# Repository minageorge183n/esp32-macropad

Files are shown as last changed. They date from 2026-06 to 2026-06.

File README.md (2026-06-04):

# 🔘 ESP32 Bluetooth + WiFi Macropad

A custom-built macropad featuring **9 programmable keys** and **2 rotary encoders**, designed for productivity, streaming, editing, and general automation.
It connects via **Bluetooth** for real-time input and **WiFi** for easy configuration through a web-based UI.

---

## ✨ Features

* 🎹 **9 Mechanical Keys**
  Fully programmable keys that can send:

  * Keyboard shortcuts
  * Media controls
  * Text strings

* 🔄 **2 Rotary Encoders**
  Each encoder supports:

  * Clockwise / Counterclockwise rotation
  * Push button click

* 📡 **Dual Connectivity**

  * **Bluetooth (BLE)** → Acts as a wireless keyboard
  * **WiFi** → Hosts a configuration web interface

* 🌐 **Web UI Configuration**

  * Access via browser (phone or PC)
  * Remap keys and encoders 
  * No need to reflash firmware for changes

---

## ⚙️ How It Works

### Bluetooth Mode

* The macropad connects to your device as a **BLE keyboard**
* Pressing keys sends predefined actions instantly

### WiFi Mode

* The device creates or connects to a WiFi network
* You access a **local web page** hosted on the ESP32
* From there, you can:

  * Change key mappings
  * Assign new actions
  * Save configurations

---

## 🚀 Getting Started

### 1. Power On

* Connect the macropad via USB or battery
* It will automatically start Bluetooth and WiFi services

### 2. Connect via Bluetooth

* Pair it like a normal keyboard
* Start using default key mappings

### 3. Access Web Interface

* Connect to the same WiFi network (or device hotspot mode)
* Open browser and go to:

  ```
  http://<device-ip>
  ```
* Configure keys and encoders from the UI

---

## 🧠 Key Mapping Capabilities

Each key can be configured to:

* 🔹 Send a single key (e.g., `A`, `Enter`)
* 🔹 Use modifiers (`Ctrl`, `Alt`, `Shift`)
* 🔹 Trigger media actions (volume, play/pause)
* 🔹 Type full strings (macros)

---

## 🎛️ Rotary Encoder Functions

Each encoder supports:

* ↻ Rotate Left → Action 1
* ↺ Rotate Right → Action 2
* ⏺ Press → Action 3

Example uses:

* Volume control
* Timeline scrubbing
* Zoom in/out

---

## 🛠️ Hardware Overview

* ESP32 microcontroller
* 9 mechanical switches
* 2 rotary encoders with push buttons
* Optional battery module

---

## 📌 Use Cases

* 🎥 Streaming (OBS, shortcuts)
* 🎨 Design (Photoshop, Illustrator)
* 🎬 Video editing (Premiere, DaVinci)
* 💻 General productivity
* 🎮 Gaming macros

---

## 🔮 Future Improvements

* Profiles switching
* OLED display support
* Cloud sync for configs
* Mobile app companion

---

## 📄 Notes

* Make sure Bluetooth is enabled on your device
* Web UI works best on modern browsers
* Keep firmware updated for new features

---

## 🤝 Contributing

This is a personal project, but ideas and improvements are always welcome.

---

## 📜 License

---

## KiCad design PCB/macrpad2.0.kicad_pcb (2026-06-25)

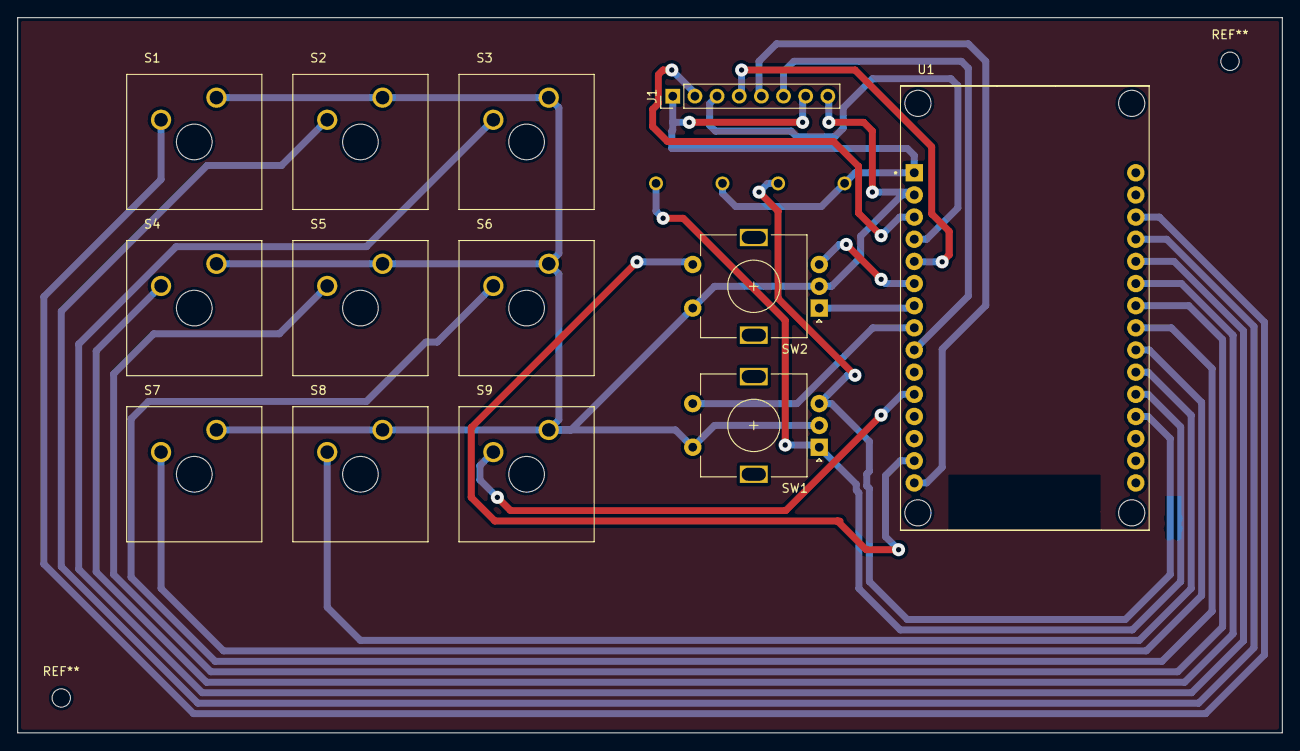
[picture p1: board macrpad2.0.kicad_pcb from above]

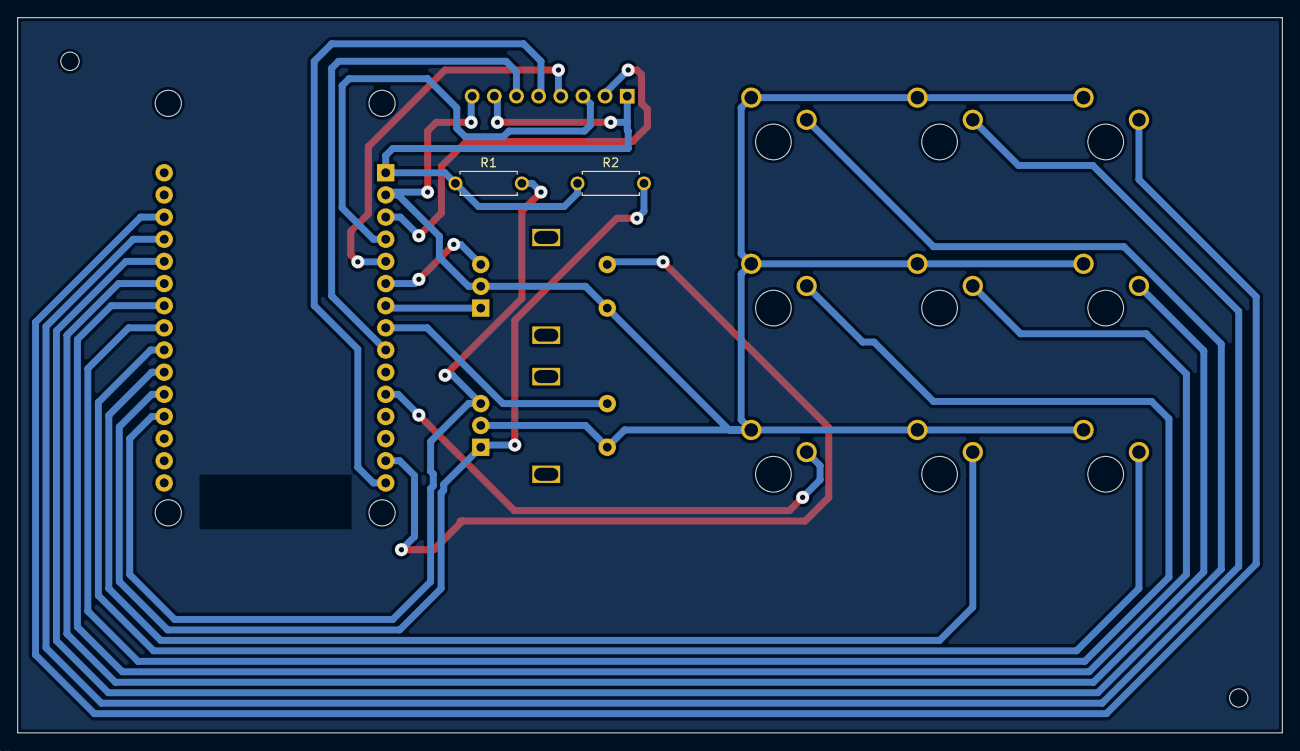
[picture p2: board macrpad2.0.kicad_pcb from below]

Board: 2 copper layers, 145.0 x 82.0 mm, 15 parts (2 on the bottom side), 22 nets.

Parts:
J1: Conn_01x08_Pin; PinHeader_1x08_P2.54mm_Vertical
R1, R2: Resistor; R_Axial_DIN0207_L6.3mm_D2.5mm_P7.62mm_Horizontal
S1, S2, S3, S4, S5, S6, S7, S8, S9: SW_MX1A-11NN
SW1, SW2: RotaryEncoder_Switch; RotaryEncoder_Alps_EC11E-Switch_Vertical_H20mm
U1: DEVKIT_V1_ESP32-WROOM-32; MODULE_DEVKIT_V1_ESP32-WROOM-32

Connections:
/d12: S2.1, U1.27 (D12)
/d13: S1.1, U1.28 (D13)
/d14: S3.1, U1.26 (D14)
GND: J1.8, S1.2, S2.2, S3.2, S4.2, S5.2, S6.2, S7.2, S8.2, S9.2, SW1.C, SW1.S2, SW2.C, SW2.S2, U1.2 (GND), U1.29 (GND)
unnamed: J1.1, J1.7, R1.1, R2.1, U1.1 (3V3)
unnamed: J1.2, U1.3 (D15)
unnamed: J1.3, U1.4 (D2)
unnamed: J1.4, U1.5 (D4)
unnamed: J1.5, U1.15 (D23)
unnamed: J1.6, U1.9 (D18)
unnamed: SW1.S1, U1.8 (D5)
unnamed: S9.1, U1.11 (D21)
unnamed: SW2.S1, U1.14 (D22)
unnamed: S6.1, U1.23 (D25)
unnamed: S5.1, U1.24 (D26)
unnamed: S4.1, U1.25 (D27)
unnamed: S8.1, U1.21 (D32)
unnamed: S7.1, U1.22 (D33)
unnamed: R1.2, SW1.B, U1.19 (D34)
unnamed: R2.2, SW1.A, U1.20 (D35)
unnamed: SW2.B, U1.6 (RX2)
unnamed: SW2.A, U1.7 (TX2)

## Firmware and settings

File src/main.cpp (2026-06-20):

#include <Arduino.h>
#include <BleKeyboard.h>
#include "macropad.h"
#include "keys.h"
#include "keymap.h"
#include "display.h"
#include "games.h"

BleKeyboard ble("Macropad", "DIY", 100);

// ── Debounce state ────────────────────────────────────────────
struct KeyDebounce {
  bool     confirmed;
  bool     raw;
  uint32_t lastChangeMs;
};

KeyDebounce keys[NUM_KEYS] = {};
KeyDebounce modeKey        = {};
uint8_t     currentMode    = 0;
bool        bleWasConnected = false;

// ── Rotary encoder state ──────────────────────────────────────
struct Encoder {
  int      pinCLK, pinDT, pinSW;
  int      lastCLK;
  bool     swConfirmed;
  bool     swRaw;
  uint32_t swLastChangeMs;
};

Encoder enc1 = { ENC1_CLK, ENC1_DT, ENC1_SW, HIGH, false, false, 0 };
Encoder enc2 = { ENC2_CLK, ENC2_DT, ENC2_SW, HIGH, false, false, 0 };

// ── Setup ─────────────────────────────────────────────────────
void setup() {
  Serial.begin(115200);

  for (int i = 0; i < NUM_KEYS; i++)
    pinMode(KEY_PINS[i], INPUT_PULLUP);

  pinMode(ENC1_CLK, INPUT);
  pinMode(ENC1_DT,  INPUT);
  pinMode(ENC1_SW,  INPUT_PULLUP);
  pinMode(ENC2_CLK, INPUT_PULLUP);
  pinMode(ENC2_DT,  INPUT_PULLUP);
  pinMode(ENC2_SW,  INPUT_PULLUP);

  enc1.lastCLK = digitalRead(ENC1_CLK);
  enc2.lastCLK = digitalRead(ENC2_CLK);

  displayInit();
  gamesInit(&tft);
  ble.begin();

  screenDirty = true;
  Serial.println("Macropad ready");
}

// ── Debounce helpers ──────────────────────────────────────────
bool debounce(KeyDebounce& k, bool reading) {
  uint32_t now = millis();
  if (reading != k.raw) { k.raw = reading; k.lastChangeMs = now; return false; }
  if ((now - k.lastChangeMs) >= DEBOUNCE_MS) {
    bool prev = k.confirmed; k.confirmed = k.raw;
    return k.raw && !prev;
  }
  return false;
}

bool debounceEncSW(Encoder& e) {
  uint32_t now     = millis();
  bool     reading = (digitalRead(e.pinSW) == LOW);
  if (reading != e.swRaw) { e.swRaw = reading; e.swLastChangeMs = now; return false; }
  if ((now - e.swLastChangeMs) >= DEBOUNCE_MS) {
    bool prev = e.swConfirmed; e.swConfirmed = e.swRaw;
    return e.swRaw && !prev;
  }
  return false;
}

int pollEncoder(Encoder& e) {
  int clk = digitalRead(e.pinCLK);
  if (clk == e.lastCLK) return 0;
  delayMicroseconds(500);
  clk = digitalRead(e.pinCLK);
  if (clk == e.lastCLK) return 0;
  e.lastCLK = clk;
  return (clk == digitalRead(e.pinDT)) ? 1 : -1;
}

// ── BLE action dispatch ───────────────────────────────────────
void executeAction(const KeyAction& action) {
  if (!ble.isConnected()) return;
  switch (action.type) {
    case KEY_SINGLE:
      for (uint8_t mod : action.modifiers) if (mod) ble.press(mod);
      ble.press(action.keycode);
      delay(10); ble.releaseAll();
      break;
    case KEY_MEDIA:
      ble.press(action.mediaKeycode);
      delay(10); ble.releaseAll();
      break;
    case KEY_STRING:
      ble.print(action.str);
      break;
    default: break;
  }
}

void executeEncoderAction(const EncoderAction& action) {
  if (!ble.isConnected()) return;
  switch (action.type) {
    case ENC_MEDIA:
      ble.press(action.mediaKeycode);
      delay(10); ble.releaseAll();
      break;
    case ENC_SINGLE:
      for (uint8_t mod : action.modifiers) if (mod) ble.press(mod);
      ble.press(action.keycode);
      delay(10); ble.releaseAll();
      break;
    default: break;
  }
}

// ── Loop ──────────────────────────────────────────────────────
void loop() {

  bool bleConnected = ble.isConnected();

  if (bleConnected != bleWasConnected) {
    bleWasConnected = bleConnected;
    screenDirty = true;
  }
  if (gamesTick()) return;

  // ── 9 keys ──────────────────────────────────────────────────
  for (int i = 0; i < NUM_KEYS; i++) {
    if (debounce(keys[i], digitalRead(KEY_PINS[i]) == LOW)) {
      const KeyAction& action = keymap[currentMode][i];
      Serial.printf("Key %d [mode %d] → %s\n", i, currentMode, action.label);
      executeAction(action);
      displaySetLastAction(action.label, i);   // pass key index for highlight
    }
  }

  // ── Encoder 1 — Volume (constant) ───────────────────────────
  int d1 = pollEncoder(enc1);
  if (d1 != 0) {
    if (d1 > 0) {
      Serial.println("Enc1 CW  → Vol+");
      ble.press(KEY_MEDIA_VOLUME_UP);
      displaySetLastAction("Vol+");   // 0xFF key = no cell highlight
    } else {
      Serial.println("Enc1 CCW → Vol-");
      ble.press(KEY_MEDIA_VOLUME_DOWN);
      displaySetLastAction("Vol-");
    }
    delay(10); ble.releaseAll();
  }
  if (debounceEncSW(enc1)) {
    Serial.println("Enc1 SW  → Mute");
    ble.press(KEY_MEDIA_MUTE);
    delay(10); ble.releaseAll();
    displaySetLastAction("Mute");
  }

  // ── Encoder 2 — Mode-aware; SW = mode change ─────────────────
  int d2 = pollEncoder(enc2);
  if (d2 != 0) {
    const EncoderMode& em = enc2Modes[currentMode];
    if (d2 > 0) {
      Serial.printf("Enc2 CW  [mode %d]\n", currentMode);
      executeEncoderAction(em.cw);
      displaySetLastAction("Enc2 CW");
    } else {
      Serial.printf("Enc2 CCW [mode %d]\n", currentMode);
      executeEncoderAction(em.ccw);
      displaySetLastAction("Enc2 CCW");
    }
  }
  if (debounceEncSW(enc2)) {
    currentMode = (currentMode + 1) % NUM_MODES;
    Serial.printf("Mode → %d (%s)\n", currentMode, enc2Modes[currentMode].label);
    screenDirty = true;
  }

  // ── Screen refresh ───────────────────────────────────────────
  if (screenDirty) {
    displayDraw(currentMode, bleConnected);
  }
  displayTick(currentMode, bleConnected);
}

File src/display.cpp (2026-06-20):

#include "display.h"

TFT_eSPI tft = TFT_eSPI();

bool     screenDirty        = true;
char     lastActionLabel[32] = "";
uint32_t lastActionMs        = 0;
bool     lastActionVisible   = false;
uint8_t  lastActionKey       = 0xFF;

// ── Internal helpers ─────────────────────────────────────────

// Cell top-left pixel coords from key index (0-8)
static void cellOrigin(int idx, int& x, int& y) {
    int col = idx % 3;
    int row = idx / 3;
    x = col * (CELL_W + CELL_GAP);
    y = GRID_TOP + row * (CELL_H + CELL_GAP);
}

// ── Pixel icons ───────────────────────────────────────────────
// All drawn relative to (ox, oy) = top-left of a 14×14 bounding box
// centred horizontally inside the cell.

static void iconVolUp(int ox, int oy, uint16_t col) {
    // speaker body
    tft.fillRect(ox,     oy+3,  4, 6, col);
    tft.fillTriangle(ox+4, oy+3, ox+9, oy, ox+9, oy+12, col);
    // three arc dots (right side)
    tft.fillRect(ox+10, oy+1,  2, 2, col);
    tft.fillRect(ox+11, oy+5,  2, 2, col);
    tft.fillRect(ox+10, oy+9,  2, 2, col);
}

static void iconVolDown(int ox, int oy, uint16_t col) {
    tft.fillRect(ox,     oy+3,  4, 6, col);
    tft.fillTriangle(ox+4, oy+3, ox+9, oy, ox+9, oy+12, col);
    // one arc dot only
    tft.fillRect(ox+10, oy+5,  2, 2, col);
}

static void iconMute(int ox, int oy, uint16_t col) {
    tft.fillRect(ox,     oy+3,  4, 6, col);
    tft.fillTriangle(ox+4, oy+3, ox+9, oy, ox+9, oy+12, col);
    // X cross
    tft.drawLine(ox+10, oy+2,  ox+13, oy+5,  col);
    tft.drawLine(ox+13, oy+2,  ox+10, oy+5,  col);
    tft.drawLine(ox+10, oy+8,  ox+13, oy+11, col);
    tft.drawLine(ox+13, oy+8,  ox+10, oy+11, col);
}

static void iconPrev(int ox, int oy, uint16_t col) {
    // stop bar + left triangle
    tft.fillRect(ox, oy, 2, 12, col);
    tft.fillTriangle(ox+3, oy+6, ox+10, oy, ox+10, oy+12, col);
}

static void iconPlay(int ox, int oy, uint16_t col) {
    tft.fillTriangle(ox, oy, ox+12, oy+6, ox, oy+12, col);
}

static void iconNext(int ox, int oy, uint16_t col) {
    tft.fillTriangle(ox, oy, ox+8, oy+6, ox, oy+12, col);
    tft.fillRect(ox+9, oy, 2, 12, col);
}

static void iconCut(int ox, int oy, uint16_t col) {
    // scissors: two circles + crossing blades
    tft.drawCircle(ox+3,  oy+3,  3, col);
    tft.drawCircle(ox+3,  oy+10, 3, col);
    tft.drawLine(ox+5,  oy+5,  ox+13, oy+12, col);
    tft.drawLine(ox+5,  oy+9,  ox+13, oy+2,  col);
}

static void iconCopy(int ox, int oy, uint16_t col) {
    // back page
    tft.drawRoundRect(ox,   oy,   9, 11, 2, col);
    // front page (filled white gap then border)
    tft.fillRoundRect(ox+3, oy+3, 9, 11, 2, C_PANEL);
    tft.drawRoundRect(ox+3, oy+3, 9, 11, 2, col);
}

static void iconPaste(int ox, int oy, uint16_t col) {
    // clipboard body
    tft.drawRoundRect(ox+1, oy+2, 10, 12, 2, col);
    // clip tab
    tft.fillRoundRect(ox+4, oy,   5,  4,  1, col);
    // ruled lines
    tft.drawFastHLine(ox+3, oy+6,  7, col);
    tft.drawFastHLine(ox+3, oy+9,  7, col);
}

static void iconNone(int ox, int oy, uint16_t col) {
    // subtle dash
    tft.drawFastHLine(ox+4, oy+6, 6, col);
}

// Dispatch icon by ActionType + label
static void drawKeyIcon(const KeyAction& ka, int cx, int iy) {
    // cx = cell left edge, iy = icon top edge
    int ox = cx + (CELL_W - 14) / 2;   // centre the 14px icon horizontally
    uint16_t col = (ka.type == KEY_NONE) ? C_TEXT_TER : C_BLUE;

    if (ka.type == KEY_NONE) { iconNone(ox, iy, col); return; }

    // Match by label string (fast on small keymap)
    const char* L = ka.label;
    if      (strcmp(L, "Vol+")    == 0) { iconVolUp(ox,   iy, C_BLUE);  }
    else if (strcmp(L, "Vol-")    == 0) { iconVolDown(ox, iy, C_BLUE);  }
    else if (strcmp(L, "Mute")    == 0) { iconMute(ox,    iy, C_RED);   }
    else if (strcmp(L, "Prev")    == 0) { iconPrev(ox,    iy, C_GREEN); }
    else if (strcmp(L, "Play")    == 0) { iconPlay(ox,    iy, C_BLUE);  }
    else if (strcmp(L, "Next")    == 0) { iconNext(ox,    iy, C_GREEN); }
    else if (strcmp(L, "Cut")     == 0) { iconCut(ox,     iy, C_AMBER); }
    else if (strcmp(L, "Copy")    == 0) { iconCopy(ox,    iy, C_AMBER); }
    else if (strcmp(L, "Paste")   == 0) { iconPaste(ox,   iy, C_AMBER); }
    else if (strcmp(L, "Save")    == 0) {
        // floppy disk outline
        tft.drawRoundRect(ox, iy, 12, 13, 1, C_BLUE);
        tft.fillRect(ox+3, iy, 5, 4, C_BLUE);          // label slot
        tft.fillRect(ox+3, iy+8, 6, 5, C_PANEL_HI);   // data window
        tft.drawRect(ox+3, iy+8, 6, 5, C_BLUE);
    }
    else if (strcmp(L, "Undo")    == 0) {
        tft.drawArc(ox+6, iy+7, 6, 4, 120, 360, C_BLUE, C_PANEL);
        tft.fillTriangle(ox, iy+3, ox+5, iy, ox+5, iy+6, C_BLUE);
    }
    else if (strcmp(L, "Redo")    == 0) {
        tft.drawArc(ox+6, iy+7, 6, 4, 0, 240, C_BLUE, C_PANEL);
        tft.fillTriangle(ox+9, iy, ox+14, iy+3, ox+9, iy+6, C_BLUE);
    }
    else if (strcmp(L, "Format")  == 0 ||
             strcmp(L, "Comment") == 0 ||
             strcmp(L, "Find")    == 0 ||
             strcmp(L, "Terminal")== 0) {
        // generic code brackets <>
        tft.drawLine(ox+1, iy+4,  ox+4,  iy+7,  C_BLUE);
        tft.drawLine(ox+4, iy+7,  ox+1,  iy+10, C_BLUE);
        tft.drawLine(ox+10,iy+4,  ox+13, iy+7,  C_BLUE);
        tft.drawLine(ox+13,iy+7,  ox+10, iy+10, C_BLUE);
    }
    else if (strcmp(L, "TODO")    == 0 ||
             strcmp(L, "Debug")   == 0) {
        // terminal prompt >_
        tft.drawLine(ox+1, iy+4, ox+4, iy+7, C_GREEN);
        tft.drawLine(ox+4, iy+7, ox+1, iy+10, C_GREEN);
        tft.drawFastHLine(ox+6, iy+11, 6, C_GREEN);
    }
    else {
        iconNone(ox, iy, C_TEXT_TER);
    }
}

// ── Menu bar ──────────────────────────────────────────────────
static void drawMenuBar(uint8_t mode, bool bleConnected) {
    // Background panel
    tft.fillRoundRect(0, 0, SCREEN_W, MENUBAR_H, 10, C_PANEL);
    // Square off bottom corners
    tft.fillRect(0, 10, SCREEN_W, MENUBAR_H - 10, C_PANEL);

    // Traffic-light dots (left side)
    tft.fillCircle(14, MENUBAR_H / 2, 5, C_TL_RED);
    tft.fillCircle(27, MENUBAR_H / 2, 5, C_TL_AMBER);
    tft.fillCircle(40, MENUBAR_H / 2, 5, C_TL_GREEN);

    // Mode name, centred
    tft.setTextDatum(MC_DATUM);
    tft.setTextColor(C_TEXT, C_PANEL);
    tft.setTextSize(1);
    tft.drawString(enc2Modes[mode].label, SCREEN_W / 2, MENUBAR_H / 2 + 1);

    // BLE pill (right side)
    uint16_t bleDot = bleConnected ? C_GREEN : C_RED;
    tft.fillRoundRect(SCREEN_W - 36, 6, 32, 16, 8, C_PANEL_HI);
    tft.fillCircle(SCREEN_W - 29, MENUBAR_H / 2, 3, bleDot);
    tft.setTextDatum(ML_DATUM);
    tft.setTextColor(bleConnected ? C_GREEN : C_RED, C_PANEL_HI);
    tft.drawString("BT", SCREEN_W - 24, MENUBAR_H / 2 + 1);
}
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

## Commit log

2026-06-03 Revise README with features and setup instructions
    Expanded README to include detailed features, usage instructions, and future improvements for the ESP32 Macropad project.
2026-06-25 Add files via upload
    gerber files without Plated through holes (using via's instead )
2026-06-25 Add files via upload
    gerber files
2026-06-25 Add files via upload
    kicad files
    [macrpad2.0.kicad_pcb, macrpad2.0.kicad_sch]
